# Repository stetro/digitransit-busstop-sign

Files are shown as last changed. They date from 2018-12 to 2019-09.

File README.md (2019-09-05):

# digitransit-busstop-sign

Finland public transport sign based on ESP8266 or ESP32

  - Queries data from digitransit with GraphQL
  - Gets current timestamp via NTP
  - Display current waiting time on Serial and I2C Display
    - I2C OLED display supported
    - 20x4 Liquid Crystal display supported

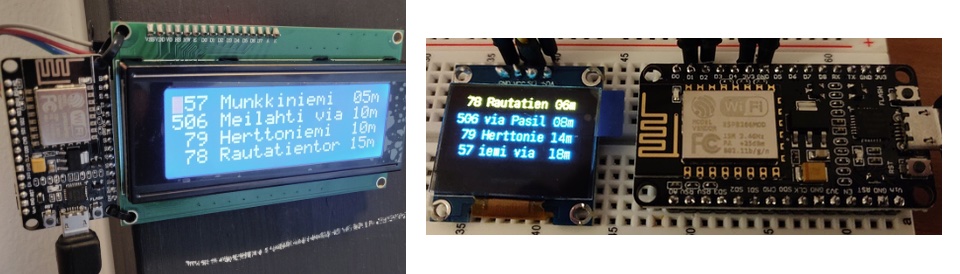
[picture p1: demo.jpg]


```
[WIFI] connecting to wifi ...
[WIFI] not connected to wifi, retry ...
[WIFI] not connected to wifi, retry ...
[WIFI] connected

[HTTP] start query ...
[HTTP] query result code: 200

[JSON] parsing response ...
[JSON] success

[NTP] query current time ...
[NTP] timestamp 1544374441

[DIGITRANSIT] Station:    Erik Spåren tie
[DIGITRANSIT] 506 Meilahti vi 03m
[DIGITRANSIT]  78 Rautatiento 05m
[DIGITRANSIT]  79 Herttoniemi 11m
[DIGITRANSIT]  57 Munkkiniemi 16m
```

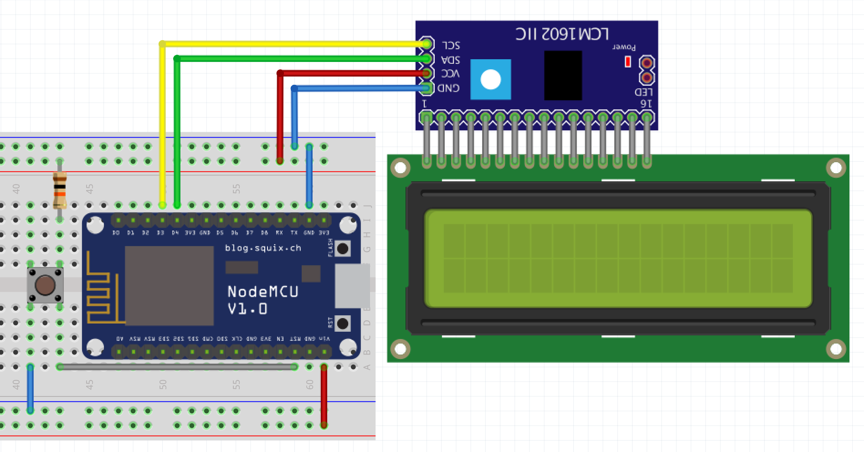
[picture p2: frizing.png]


## Features

* Connects to your WiFi
* Shows realtime timetables for bus, tram and metro stations
* Shows availables bikes in bike stations
* Turns off after 5 mimnutes
* Easy configuration with wifi hotstop web-ui
* Send `'c'` via serial during bootup for reconfiguration
* Turns off after `n` minutes. (set to 0 to run endlessly)

## Usage

How to build your own Station Sign:

1. Set all needed variables in `platformio.ini`
  - `display` - `0` for Liquid Crystal Display and `1` for OLED Display
  - `display_address` - I2C display address
2. Install PlatformIO and flash NodeMCU
  - `pip install -U platformio`
  - `platformio update`
  - `platformio run --target upload`
3. Power the device and wait 20 Seconds until access point is shown on the display
4. Connect to it and open the shown address in your browser
5. Apply configurations as shown in the web ui

> Enclosure examples for both display types can be found in `case/`.

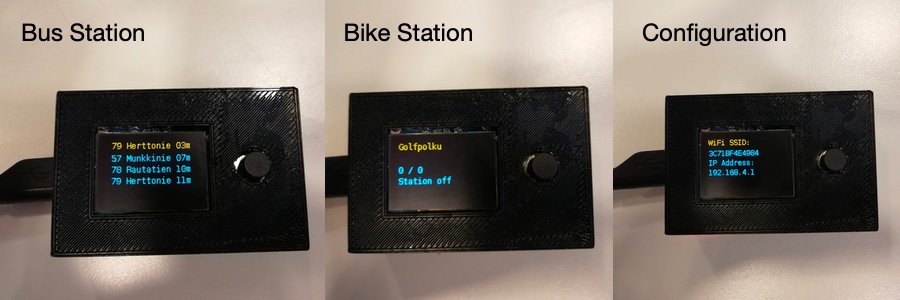
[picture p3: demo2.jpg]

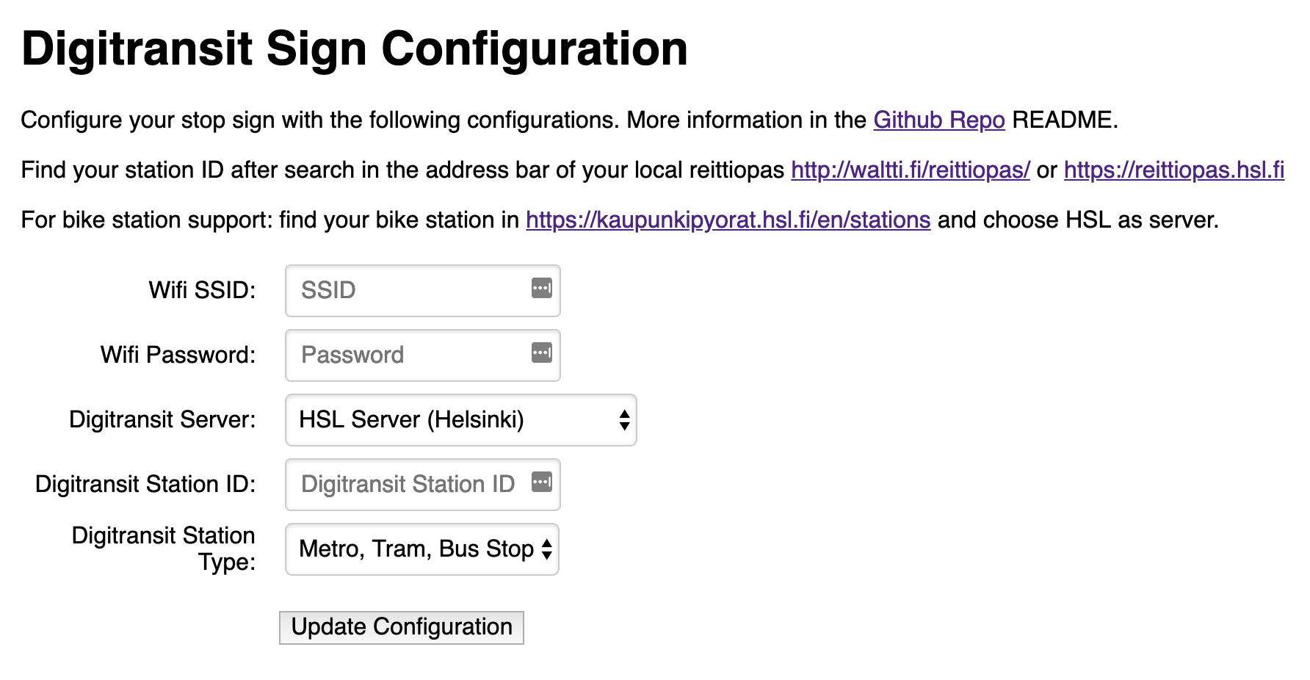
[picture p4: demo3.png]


### Partlist

For the basic usage only the NodeMcu and LCD display is needed.

* NodeMCU ESP32 or NodeMCU ESP8266
* LCD Display 20x4 with I2C Adapter or OLED I2C Display
* [Tactile Push Button]
* [10k Resistor]
* [Lithium Ion Battery 3.7]
* [5V stepup board with charging circuit]

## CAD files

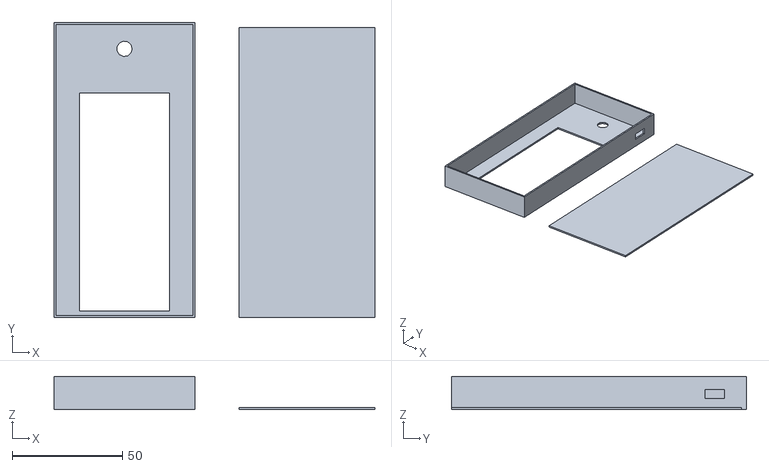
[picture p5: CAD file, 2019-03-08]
case/liquid_crystal_display_case.stl
145.7 x 134.0 x 15.0

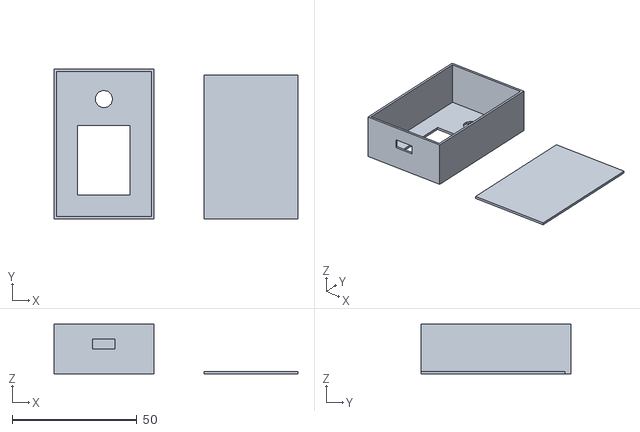
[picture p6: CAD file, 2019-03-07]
case/oled_display_case.stl
97.7 x 60.0 x 20.0

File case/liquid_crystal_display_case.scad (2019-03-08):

 width = 64;
length = 134;
depth = 15;
wall = 1;
fitting = 0.001;

display_width = 41;
display_length = 99;
snug_fit = 0.3;
union(){
    difference(){
        // case
        cube([width, length, depth]);
        // case cutout
        translate([wall, wall,wall])
        cube([width-2*wall, length-2*wall, depth-wall+fitting]);    
        // display cutout
        translate([(width-display_width)/2,3,-fitting])
        cube([display_width, display_length, wall+2*fitting]);
        // button cutout
        translate([width/2,length - 12,0])
        cylinder(wall*2+fitting, 3.5, 3.5, true);
        // case cutout
        translate([width-wall-fitting, length - 9 - 10,depth-10])
        cube([wall+2*fitting,9,4]);
    }

    
    // lid
    translate([width+20,0,0])
    cube([width - 2*wall - snug_fit, length- 2*wall - snug_fit, wall]);
}

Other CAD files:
case/oled_display_case.scad

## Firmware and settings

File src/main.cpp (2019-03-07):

#include <Arduino.h>

#ifdef NODE_MCU_ESP8266
#include <ESP8266WiFi.h>
#define ENDLESS_DEEPSLEEP 0
#endif

#ifdef NODE_MCU_ESP32
#include <WiFi.h>
#define ENDLESS_DEEPSLEEP -1
#endif

#define MAX_WIFI_RETRIES 20

#include <configuration.h>
#include <digitransit-display.h>
#include <digitransit.h>

Digitransit digitransit;
Configuration configuration;
ConfigurationData* configuration_data;

#if DIGITRANSIT_DISPLAY == 0
LiquidCrystalDisplay display;
#else
OledDisplay display;
#endif

int show_counter = 0;
int wifi_connection_retries = 0;
bool wifi_configuration_mode = false;
bool wifiConnected() { return (WiFi.status() == WL_CONNECTED); }

void deepSleep() {
  display.turnOff();
  Serial.println("[ESP] deep sleep");
  delay(1000);
  ESP.deepSleep(ENDLESS_DEEPSLEEP);
}

void setup() {
  Serial.begin(115200);

  display.init();
  display.showLoadingScreen();

  configuration_data = configuration.get_configuration();
  if (!(configuration_data->eeprom_check[0] == 'O' &&
        configuration_data->eeprom_check[1] == 'K')) {
    WiFi.disconnect();
    wifi_configuration_mode = true;
    configuration.init();
    delay(1000);
    display.clear();
    display.showConfiguration(&configuration);
    return;
  }

  Serial.println("[WIFI] connecting to wifi ...");
  WiFi.begin(configuration_data->ssid, configuration_data->password);
}

void loop() {
  if (Serial.available() > 0) {
    if (Serial.read() == 'c') {
      configuration.clear();
    }
  }
  if (wifiConnected() && !wifi_configuration_mode) {
    Serial.println("[WIFI] connected");
    while (true) {
      bool querySucceeded = false;
      if (configuration_data->bike_station) {
        querySucceeded = digitransit.queryBikeStation(
            configuration_data->digitransit_server_id,
            configuration_data->digitransit_station_id);
      } else {
        querySucceeded = digitransit.queryTimetable(
            configuration_data->digitransit_server_id,
            configuration_data->digitransit_station_id);
      }

      if (querySucceeded) {
        display.clear();
        display.updateTimetable(&digitransit);
        if (configuration_data->bike_station) {
          display.showBikeStation();
        } else {
          display.showTimetable();
        }
        delay(60000);
        show_counter++;
        if (show_counter >= configuration_data->turnoff &&
            configuration_data->turnoff > 0) {
          deepSleep();
        }
      } else {
        display.clear();
        display.showError();
        delay(10000);
      }
    }
    display.clear();
    display.turnOff();
  } else if (!wifi_configuration_mode) {
    Serial.println("[WIFI] not connected to wifi, still trying ...");
    delay(1000);
    wifi_connection_retries++;
    if (wifi_connection_retries >= MAX_WIFI_RETRIES) {
      WiFi.disconnect();
      wifi_configuration_mode = true;
      configuration.init();
      delay(1000);
      display.clear();
      display.showConfiguration(&configuration);
    }
  } else {
    // Configuration Async Webserver
  }
}

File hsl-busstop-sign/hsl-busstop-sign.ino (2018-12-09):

/**
  HSL Bus Station Query
  - Queries data from HSl viw GraphQL
  - Gets current timestamp via NTP
  - Display current waiting time on Serial (display is coming)
*/

#include <Arduino.h>
#include <ESP8266WiFiMulti.h>

#include "hsl.h"

ESP8266WiFiMulti WiFiMulti;
Hsl hsl;

void setup() {
  Serial.begin(115200);
  delay(1000);
  Serial.println("[WIFI] connecting to wifi ...");
  WiFi.mode(WIFI_STA);
  WiFiMulti.addAP("***", "***");
}

void loop() {
  if (wifiConnected()) {
    Serial.println("[WIFI] connected");

    hsl.queryTimetable(HSL_QUERY_1);
    if (hsl.success) {
      hsl.timetable;
    } else {
    }
    delay(30 * 1000);
    hsl.queryTimetable(HSL_QUERY_2);
    delay(30 * 1000);

  } else {
    Serial.println("[WIFI] not connected to wifi, retry ...");
  }

  delay(1000);
}

bool wifiConnected() { return (WiFiMulti.run() == WL_CONNECTED); }

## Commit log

2018-12-13 add sketch fritzing
    [hsl-busstop-sign.fzz]
2019-01-20 switch liquid crystal i2c library
2019-02-02 add ESP32 Support
2019-02-04 add switch for tampere api
2019-02-04 cleanup fritzing
    [hsl-busstop-sign.fzz]
2019-02-27 remove PROGMEM http://forum.arduino.cc/index.php?topic=141571.0#4
2019-03-05 use Wifi.begin() for initial setup in case of clean flashing
2019-03-07 implement endless deepsleep for both devices
2019-03-07 add cases
    [liquid_crystal_display_case.scad, liquid_crystal_display_case.stl, oled_display_case.scad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]
2019-03-07 add lid to liquid_crystal_display_case
    [liquid_crystal_display_case.scad, liquid_crystal_display_case.stl]
2019-03-08 change size
    [liquid_crystal_display_case.scad, liquid_crystal_display_case.stl]
2019-03-08 remove lid
    [liquid_crystal_display_case.stl]
2019-03-08 add back lid
    [liquid_crystal_display_case.scad, liquid_crystal_display_case.stl]
